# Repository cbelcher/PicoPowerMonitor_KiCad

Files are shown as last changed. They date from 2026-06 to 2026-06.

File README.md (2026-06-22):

# Pico Power Monitor KiCad Files

This the PCB project files, for the Pico Power Monitor.  I've included everything you need to open up this project in KiCad version 10.0.3 or newer.  Also included PCWay zip folder that you just need to drop on there site and checkout.  KiCad has the complete BOM needed to populate the project.

## Project is broken up into 4 sub-projects.

  - KiCad Custom PCB Design - This Repo.

	- PCBWay Shared Projects (Direct link [here](https://www.pcbway.com/project/shareproject/Pico_Power_Monitor_e0ff12c4.html))

  - PicoPowerMonitor - This is the Windows 11 application, completely optional.  The PicoPowerMonitor can and does run without this application.
  
	- Repo: /PicoPowerMonitor (Direct link [here](https://github.com/cbelcher/PicoPowerMonitor))
 
  - MicroPhython code to drive the hardware side of things.
		    
    - Repo: /RP2040PowerMonitor  (Direct link [here](https://github.com/cbelcher/RP2040PowerMonitor))
        This is the project that runs on the RP2040-Zero.  Current MicroPython firmware 1.28.
      
  - FreeCAD 3D Printed Case Design. (Direct link [here](https://github.com/cbelcher/PicoPowerMonitor_FreeCAD))

## CAD and Finished PCB Images

- Just unpacked PCB's from PCBWay.com
<p align="center">
PCB's
</p>

- 3D Render Shots of PCB from KiCad.

- Top with Through-hole Components
<p align="center">

</p>

- Top with Through-hole & SMD Components
<p align="center">

</p>

- Top No Compnents
<p align="center">

</p>

- Bottom shot
<p align="center">

</p>

- 1st unit off the projection line, getting put through its paces.
<p align="center">


## License

This project is licensed under the MIT License - see the [LICENSE](https://www.google.com/search?q=LICENSE) file for details.

## Acknowledgments

* KiCad.org for their amazing open-source CAD software.  [FreeCad.org](https://freecad.org))

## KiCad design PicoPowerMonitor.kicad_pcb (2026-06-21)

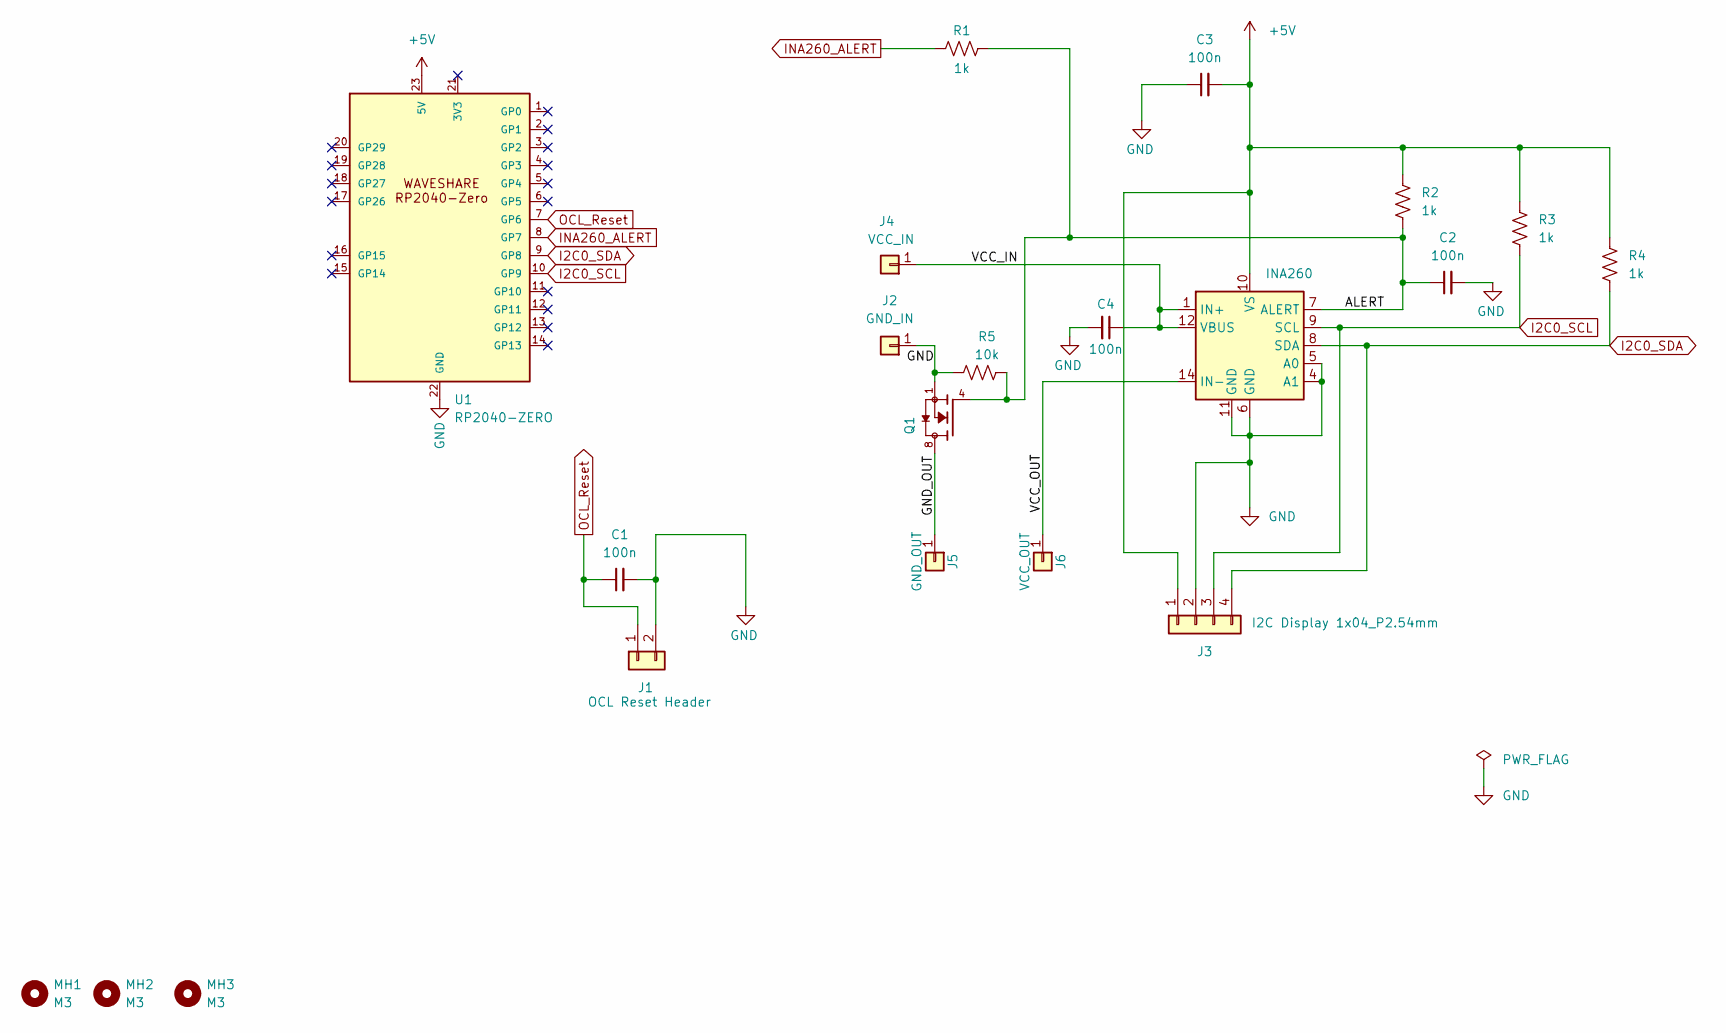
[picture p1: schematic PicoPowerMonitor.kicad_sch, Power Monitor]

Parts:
C1, C2, C3, C4: 100n; C_0603_1608Metric_Pad1.08x0.95mm_HandSolder
J1: OCL Reset Header; PinHeader_1x02_P2.54mm_Vertical
J2: GND_IN; 1_Banana_Jack_4mm_Panel_Cliff
J3: I2C Display 1x04_P2.54mm; PinHeader_1x04_P2.54mm_Vertical
J4: VCC_IN; 1_Banana_Jack_4mm_Panel_Cliff
J5: GND_OUT; 1_Banana_Jack_4mm_Panel_Cliff
J6: VCC_OUT; 1_Banana_Jack_4mm_Panel_Cliff
MH1, MH2, MH3: M3; MountingHole_3.2mm_M3
Q1: BSC007N04LS6ATMA1; TRANS_BSC007N04LS6ATMA1; DigiKey_Part_Number BSC007N04LS6ATMA1CT-ND
R1, R2, R3, R4: 1k; R_0603_1608Metric_Pad0.98x0.95mm_HandSolder
R5: 10k; R_0603_1608Metric_Pad0.98x0.95mm_HandSolder
U1: RP2040-ZERO; MODULE_RP2040-ZERO_Castellet_THT_SMD
U2: INA260; 1_INA260_TSSOP-16_4.4x5mm_P0.65mm

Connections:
+5V: C3.2, J3.1, R2.1, R3.1, R4.1, U1.23 (5V), U2.10 (VS)
/ALERT: C2.1, Q1.4, R1.2, R2.2, R5.1, U2.7 (ALERT)
/GND_OUT: J5.1 (Pin_1_1), Q1.8
/VCC_IN: C4.1, J4.1 (Pin_1_1), U2.1 (IN+), U2.12 (VBUS)
/VCC_OUT: J6.1 (Pin_1_1), U2.14 (IN-)
GND: C1.2, C2.2, C3.1, C4.2, J1.2, J2.1 (Pin_1_1), J3.2, Q1.1, R5.2, U1.22 (GND), U2.4 (A1), U2.5 (A0), U2.6 (GND), U2.11 (GND)
I2C0_SCL: J3.3, R3.2, U1.10 (GP9), U2.9 (SCL)
I2C0_SDA: J3.4, R4.2, U1.9 (GP8), U2.8 (SDA)
INA260_ALERT: R1.1, U1.8 (GP7)
OCL_Reset: C1.1, J1.1, U1.7 (GP6)

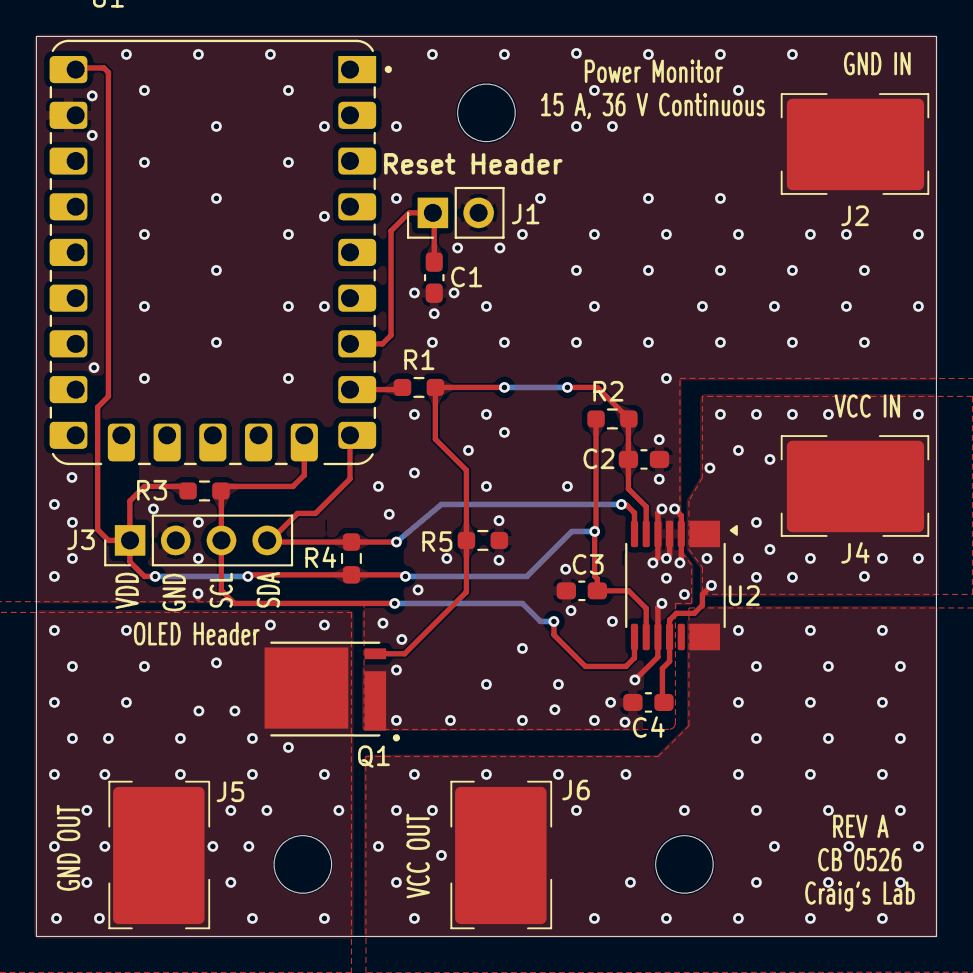
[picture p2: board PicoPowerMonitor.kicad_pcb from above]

Board: 2 copper layers, 50.0 x 50.0 mm, 21 parts (0 on the bottom side), 10 nets.

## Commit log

2026-06-21 KiCad 10.0.3 production files
    [PicoPowerMonitor.kicad_pcb, PicoPowerMonitor.kicad_sch]
2026-06-21 Added PCBWay zip file. Everything you need to have to PCB created by PCBWay.
    [PicoPowerMonitor.kicad_pcb]
2026-06-21 First README commit
    This README includes project details for the Pico Power Monitor, including links to sub-projects, images of the PCB, and licensing information.
2026-06-21 Update README with PCBWay project link
    Added direct link to PCBWay shared projects in README.
2026-06-22 Fix links in README.md
    Corrected links in the README for RP2040PowerMonitor and FreeCAD case design.
